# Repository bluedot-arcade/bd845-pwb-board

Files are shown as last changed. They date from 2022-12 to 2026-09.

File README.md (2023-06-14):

<p align="right">
    
      
</p>
<br><br>
<p align="center">
    <h1 align="center">BD845-PWB IO Board</h1>
    <p align="center">A clone of the original Konami GN845-PWB(B) Stage I/O board for DDR machines.</p>
    <p align="center"><strong><a href="https://github.com/bluedot-arcade/bd845-pwb-firmware">Go to firmware repository</a></strong></p>
    <p align="center"><strong><a href="https://docs.bluedotarcade.com/boards/bd845-pwb">Explore the docs</a></strong></p>
    <br><br>
</p>

<p align="center">A render of the board from the front.</p>

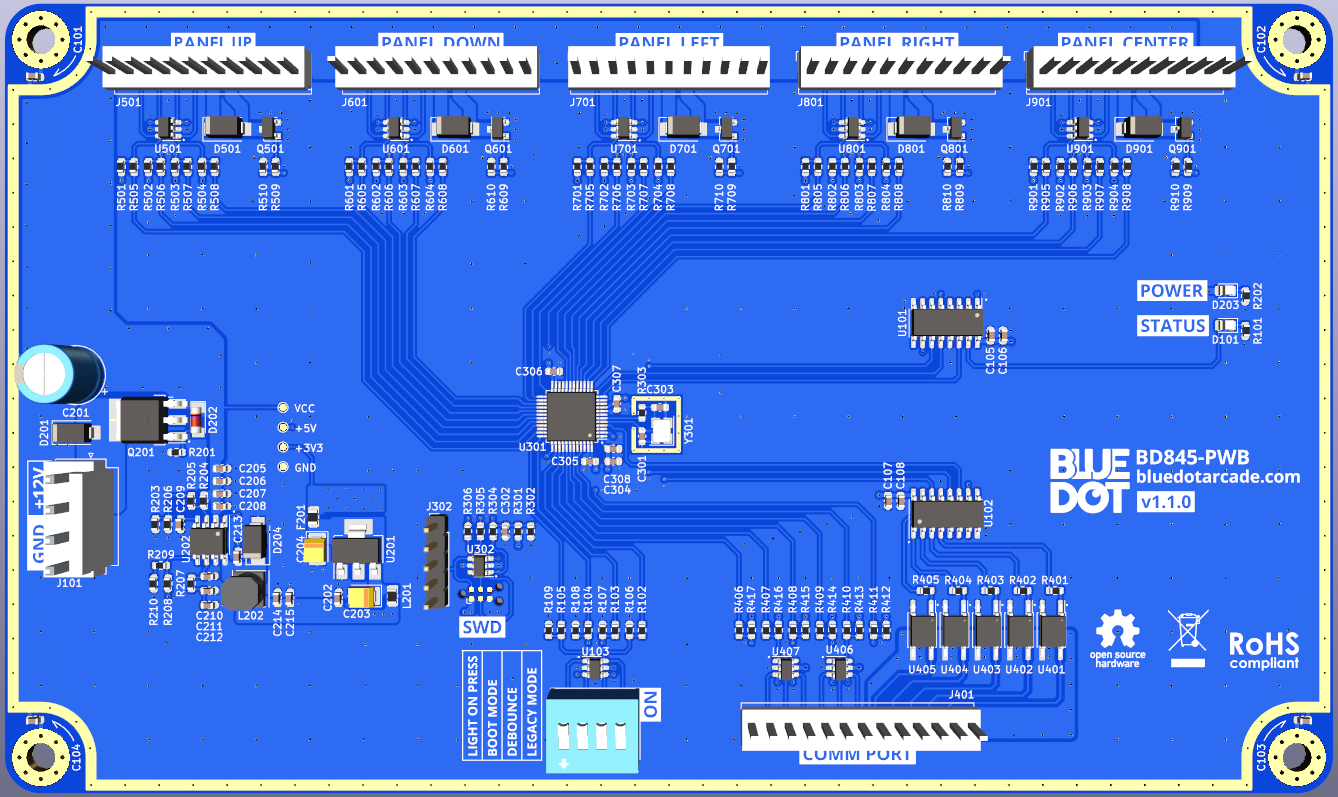
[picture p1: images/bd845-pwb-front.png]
BD845-PWB Front


## About the project

The goal of the project is to replicate the original Konami GN845-PWB(B) Stage I/O board by designing a drop in replacement board for future-proofing DDR cabinets.

It emulates the original DDR Stage I/O communication protocol boot sequence allowing to run the game without an I/O Check Bypass. Other protocol features are currently not supported.

It also provides additional features such as debouncing and a Light-On-Press mode that lights up the arrow light when pressed without the need of an external lights driver board.

The board can be re-programmed with a custom/updated firmware. The latest version of the firmware can be found [here](https://github.com/bluedot-arcade/bd845-pwb-firmware).

For more information read the [docs](https://docs.bluedotarcade.com/boards/bd845-pwb).

<p align="right">(<a href="#readme-top">back to top</a>)</p>

## Project structure

* [/fab/](/fab/) - the files required for fabbrication that includes gerbers, drills and assembly files.
* [/kicad/](/kicad/) -  the kicad project files.
* [/images/](/images/) - images and renders.
* [/sch_bd845-pwb.pdf](/sch_bd845-pwb.pdf) - the board's schematic.
* [/draw_bd845-pwb.pdf](/draw_bd845-pwb.pdf) - the board's mechanical drawings.
* [/bom_bd845-pwb.csv](/bom_bd845-pwb.csv) - the board's bill of materials.
* [/ibom_bd845-pwb.html](/ibom_bd845-pwb.html) - an interactive bill of materials very useful for manual assembly.

<p align="right">(<a href="#readme-top">back to top</a>)</p>

## Images and renders

PCB Front layer:

BD845-PWB Front

PCB Back layer:

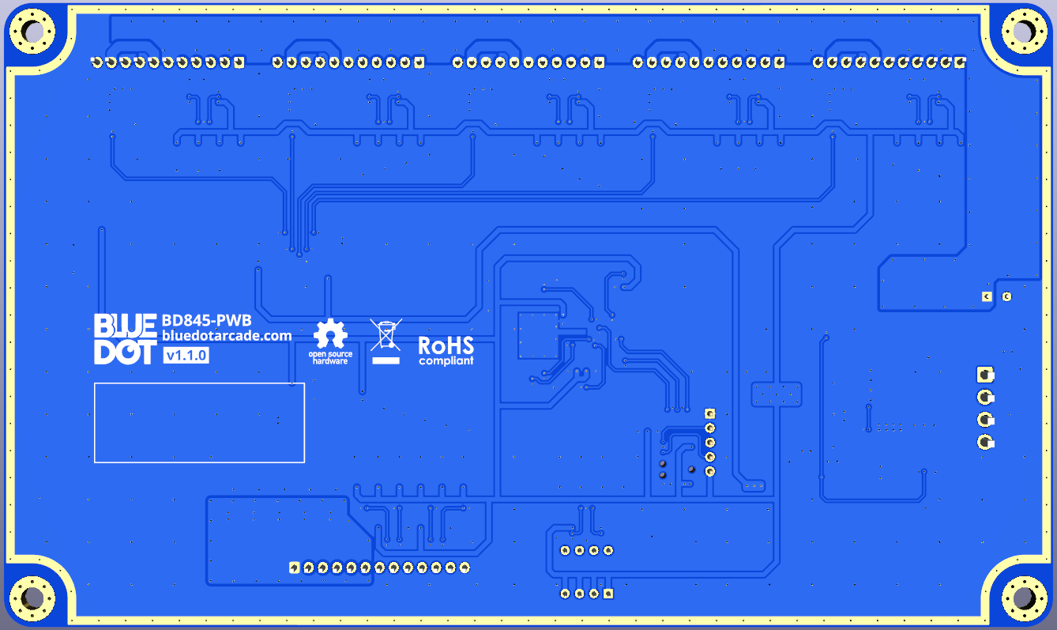
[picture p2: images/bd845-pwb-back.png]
BD845-PWB Back


Original Konami GN845-PWB:

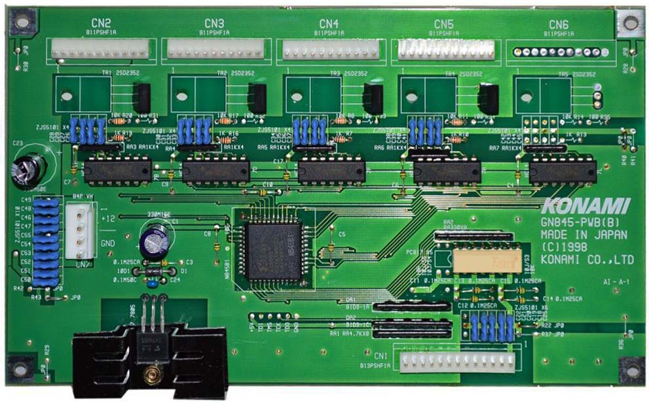
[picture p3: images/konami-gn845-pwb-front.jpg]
GN845-PWB Front


<p align="right">(<a href="#readme-top">back to top</a>)</p>

## License

Distributed under the CERN OHL S 2 License. See [LICENSE.txt] for more information.

<p align="right">(<a href="#readme-top">back to top</a>)</p>

## Acknowledgments

* [NaokiS] - for providing valuable information about the original DDR stage IO communication protocol.
* [Marco Ruggiero] - for designing the BlueDot logo and beta-testing the board on its own cabinet.
* [Mattia Pini] - for lending me his KSYS573 computer to carry out tests.
* [MameDev] - for opensourcing the KSYS573 Boot IO check emulation which this board is based on.
* [InteractiveHtmlBom] - the Kicad plugin used to generate the interactive BOM.
* [Kicad] - for allowing me to design this board for free!

<p align="right">(<a href="#readme-top">back to top</a>)</p>

[NaokiS]: http://nsaito.co.uk/
[Marco Ruggiero]: https://www.instagram.com/ruggiero.design/
[Mattia Pini]: https://github.com/martirius
[MameDev]: https://github.com/mamedev/mame/blob/master/src/mame/konami/ksys573.cpp
[InteractiveHtmlBom]: https://github.com/openscopeproject/InteractiveHtmlBom
[Kicad]: https://www.kicad.org/
[LICENSE.txt]: /LICENSE.txtschematic

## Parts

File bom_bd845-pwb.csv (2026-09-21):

Reference | Value | Footprint | Datasheet | JLCPCB Part #
C101 | 1n | Capacitor_SMD:C_0603_1608Metric |  | C1588
C102 | 1n | Capacitor_SMD:C_0603_1608Metric |  | C1588
C103 | 1n | Capacitor_SMD:C_0603_1608Metric |  | C1588
C104 | 1n | Capacitor_SMD:C_0603_1608Metric |  | C1588
C105 | 10n | Capacitor_SMD:C_0603_1608Metric |  | C57112
C106 | 100n | Capacitor_SMD:C_0603_1608Metric |  | C14663
C107 | 100n | Capacitor_SMD:C_0603_1608Metric |  | C14663
C108 | 10n | Capacitor_SMD:C_0603_1608Metric |  | C57112
C201 | 330u | Capacitor_THT:CP_Radial_D8.0mm_P3.50mm |  | C109394
C202 | 100n | Capacitor_SMD:C_0603_1608Metric |  | C14663
C203 | 22u | Capacitor_Tantalum_SMD:CP_EIA-3528-15_AVX-H |  | C8020
C204 | 22u | Capacitor_Tantalum_SMD:CP_EIA-3528-15_AVX-H |  | C8020
C205 | 10u | Capacitor_SMD:C_0603_1608Metric |  | C96446
C206 | 10u | Capacitor_SMD:C_0603_1608Metric |  | C96446
C207 | 10n | Capacitor_SMD:C_0603_1608Metric |  | C57112
C208 | 1n | Capacitor_SMD:C_0603_1608Metric |  | C1588
C209 | 10n | Capacitor_SMD:C_0603_1608Metric |  | C57112
C210 | 6p8 | Capacitor_SMD:C_0603_1608Metric |  | C1679
C211 | 2n7 | Capacitor_SMD:C_0603_1608Metric |  | C1609
C212 | 2n7 | Capacitor_SMD:C_0603_1608Metric |  | C1609
C213 | 100n | Capacitor_SMD:C_0603_1608Metric |  | C14663
C214 | 10u | Capacitor_SMD:C_0603_1608Metric |  | C96446
C215 | 10u | Capacitor_SMD:C_0603_1608Metric |  | C96446
C301 | 10p | Capacitor_SMD:C_0603_1608Metric |  | C1634
C302 | 100n | Capacitor_SMD:C_0603_1608Metric |  | C14663
C303 | 10p | Capacitor_SMD:C_0603_1608Metric |  | C1634
C304 | 10u | Capacitor_SMD:C_0603_1608Metric |  | C96446
C305 | 100n | Capacitor_SMD:C_0603_1608Metric |  | C14663
C306 | 100n | Capacitor_SMD:C_0603_1608Metric |  | C14663
C307 | 100n | Capacitor_SMD:C_0603_1608Metric |  | C14663
C308 | 100n | Capacitor_SMD:C_0603_1608Metric |  | C14663
D101 | Status | LED_SMD:LED_0805_2012Metric |  | C2296
D201 | SMAJ15CA | Diode_SMD:D_SMA |  | C19077536
D202 | 5V6 | Diode_SMD:D_MiniMELF |  | C19077402
D203 | Power | LED_SMD:LED_0805_2012Metric |  | C2297
D204 | SS34 | Diode_SMD:D_SMA |  | C8678
D501 | SS34 | Diode_SMD:D_SMA |  | C8678
D601 | SS34 | Diode_SMD:D_SMA |  | C8678
D701 | SS34 | Diode_SMD:D_SMA |  | C8678
D801 | SS34 | Diode_SMD:D_SMA |  | C8678
D901 | SS34 | Diode_SMD:D_SMA |  | C8678
F201 | BSMD0805-035 | Fuse:Fuse_0805_2012Metric |  | C883107
H101 | MountingHole_Pad | MountingHole:MountingHole_4mm_Pad_Via
H102 | MountingHole_Pad | MountingHole:MountingHole_4mm_Pad_Via
H103 | MountingHole_Pad | MountingHole:MountingHole_4mm_Pad_Via
H104 | MountingHole_Pad | MountingHole:MountingHole_4mm_Pad_Via
J101 | JST_VH_B4P | Connector_JST:JST_VH_B4P-VH_1x04_P3.96mm_Vertical |  | C493148
J301 | TC2030-MCP-NL | Connector:Tag-Connect_TC2030-IDC-NL_2x03_P1.27mm_Vertical | http://ww1.microchip.com/downloads/en/DeviceDoc/TC2030-MCP-NL_PCB_Footprint_RevD.pdf
J302 | PinHeader_01x05 | Connector_PinHeader_2.54mm:PinHeader_1x05_P2.54mm_Vertical |  | C6332198
J401 | JST_B13P_SHF_1AA | ProjectLibrary:JST_NH_B13P-SHF-1AA_1x13_P2.50mm_Vertical |  | C160368
J501 | JST_B11P_SHF_1AA | ProjectLibrary:JST_NH_B11P-SHF-1AA_1x11_P2.50mm_Vertical |  | C160366
J601 | JST_B11P_SHF_1AA | ProjectLibrary:JST_NH_B11P-SHF-1AA_1x11_P2.50mm_Vertical |  | C160366
J701 | JST_B11P_SHF_1AA | ProjectLibrary:JST_NH_B11P-SHF-1AA_1x11_P2.50mm_Vertical |  | C160366
J801 | JST_B11P_SHF_1AA | ProjectLibrary:JST_NH_B11P-SHF-1AA_1x11_P2.50mm_Vertical |  | C160366
J901 | JST_B11P_SHF_1AA | ProjectLibrary:JST_NH_B11P-SHF-1AA_1x11_P2.50mm_Vertical |  | C160366
L201 | 100R | Resistor_SMD:R_0805_2012Metric |  | C1015
L202 | 22u | Inductor_SMD:L_Taiyo-Yuden_NR-50xx |  | C68434
Q201 | AOD409 | Package_TO_SOT_SMD:TO-252-3_TabPin2 | https://datasheet.lcsc.com/lcsc/1811091710_Alpha---Omega-Semicon-AOD409_C36220.pdf | C36220
Q501 | ZXMS6004FFTA | ProjectLibrary:SOT23F | https://datasheet.lcsc.com/lcsc/2005131032_Diodes-Incorporated-ZXMS6004FFTA_C95063.pdf | C95063
Q601 | ZXMS6004FFTA | ProjectLibrary:SOT23F | https://datasheet.lcsc.com/lcsc/2005131032_Diodes-Incorporated-ZXMS6004FFTA_C95063.pdf | C95063
Q701 | ZXMS6004FFTA | ProjectLibrary:SOT23F | https://datasheet.lcsc.com/lcsc/2005131032_Diodes-Incorporated-ZXMS6004FFTA_C95063.pdf | C95063
Q801 | ZXMS6004FFTA | ProjectLibrary:SOT23F | https://datasheet.lcsc.com/lcsc/2005131032_Diodes-Incorporated-ZXMS6004FFTA_C95063.pdf | C95063
Q901 | ZXMS6004FFTA | ProjectLibrary:SOT23F | https://datasheet.lcsc.com/lcsc/2005131032_Diodes-Incorporated-ZXMS6004FFTA_C95063.pdf | C95063
R101 | 1k | Resistor_SMD:R_0603_1608Metric |  | C21190
R102 | 150R | Resistor_SMD:R_0603_1608Metric |  | C22808
R103 | 150R | Resistor_SMD:R_0603_1608Metric |  | C22808
R104 | 150R | Resistor_SMD:R_0603_1608Metric |  | C22808
R105 | 150R | Resistor_SMD:R_0603_1608Metric |  | C22808
R106 | 10k | Resistor_SMD:R_0603_1608Metric |  | C25804
R107 | 10k | Resistor_SMD:R_0603_1608Metric |  | C25804
R108 | 10k | Resistor_SMD:R_0603_1608Metric |  | C25804
R109 | 10k | Resistor_SMD:R_0603_1608Metric |  | C25804
R201 | 10k | Resistor_SMD:R_0603_1608Metric |  | C25804
R202 | 1k | Resistor_SMD:R_0603_1608Metric |  | C21190
R203 | 10k | Resistor_SMD:R_0603_1608Metric |  | C25804
R204 | 100k | Resistor_SMD:R_0603_1608Metric |  | C25803
R205 | 10k | Resistor_SMD:R_0603_1608Metric |  | C25804
R206 | 10k | Resistor_SMD:R_0603_1608Metric |  | C25804
R207 | 6k8 | Resistor_SMD:R_0603_1608Metric |  | C23212
R208 | 10k | Resistor_SMD:R_0603_1608Metric |  | C25804
R209 | 150R | Resistor_SMD:R_0603_1608Metric |  | C22808
R210 | 1k8 | Resistor_SMD:R_0603_1608Metric |  | C4177
R301 | 10k | Resistor_SMD:R_0603_1608Metric |  | C25804
R302 | NC | Resistor_SMD:R_0603_1608Metric
R303 | 47R | Resistor_SMD:R_0603_1608Metric |  | C23182
R304 | 150R | Resistor_SMD:R_0603_1608Metric |  | C22808
R305 | 150R | Resistor_SMD:R_0603_1608Metric |  | C22808
R306 | 150R | Resistor_SMD:R_0603_1608Metric |  | C22808
R401 | 330R | Resistor_SMD:R_0603_1608Metric |  | C23138
R402 | 330R | Resistor_SMD:R_0603_1608Metric |  | C23138
R403 | 330R | Resistor_SMD:R_0603_1608Metric |  | C23138
R404 | 330R | Resistor_SMD:R_0603_1608Metric |  | C23138
R405 | 330R | Resistor_SMD:R_0603_1608Metric |  | C23138
R406 | 150R | Resistor_SMD:R_0603_1608Metric |  | C22808
R407 | 150R | Resistor_SMD:R_0603_1608Metric |  | C22808
R408 | 150R | Resistor_SMD:R_0603_1608Metric |  | C22808
R409 | 150R | Resistor_SMD:R_0603_1608Metric |  | C22808
R410 | 150R | Resistor_SMD:R_0603_1608Metric |  | C22808
R411 | 150R | Resistor_SMD:R_0603_1608Metric |  | C22808
R412 | 10k | Resistor_SMD:R_0603_1608Metric |  | C25804
R413 | 10k | Resistor_SMD:R_0603_1608Metric |  | C25804
R414 | 10k | Resistor_SMD:R_0603_1608Metric |  | C25804
R415 | 10k | Resistor_SMD:R_0603_1608Metric |  | C25804
R416 | 10k | Resistor_SMD:R_0603_1608Metric |  | C25804
R417 | 10k | Resistor_SMD:R_0603_1608Metric |  | C25804
R501 | 10k | Resistor_SMD:R_0603_1608Metric |  | C25804
R502 | 10k | Resistor_SMD:R_0603_1608Metric |  | C25804
R503 | 10k | Resistor_SMD:R_0603_1608Metric |  | C25804
R504 | 10k | Resistor_SMD:R_0603_1608Metric |  | C25804
R505 | 150R | Resistor_SMD:R_0603_1608Metric |  | C22808
R506 | 150R | Resistor_SMD:R_0603_1608Metric |  | C22808
R507 | 150R | Resistor_SMD:R_0603_1608Metric |  | C22808
R508 | 150R | Resistor_SMD:R_0603_1608Metric |  | C22808
R509 | 0R | Resistor_SMD:R_0603_1608Metric |  | C21189
R510 | 10k | Resistor_SMD:R_0603_1608Metric |  | C25804
R601 | 10k | Resistor_SMD:R_0603_1608Metric |  | C25804
R602 | 10k | Resistor_SMD:R_0603_1608Metric |  | C25804
R603 | 10k | Resistor_SMD:R_0603_1608Metric |  | C25804
R604 | 10k | Resistor_SMD:R_0603_1608Metric |  | C25804
R605 | 150R | Resistor_SMD:R_0603_1608Metric |  | C22808
R606 | 150R | Resistor_SMD:R_0603_1608Metric |  | C22808
R607 | 150R | Resistor_SMD:R_0603_1608Metric |  | C22808
R608 | 150R | Resistor_SMD:R_0603_1608Metric |  | C22808
R609 | 0R | Resistor_SMD:R_0603_1608Metric |  | C21189
R610 | 10k | Resistor_SMD:R_0603_1608Metric |  | C25804
R701 | 10k | Resistor_SMD:R_0603_1608Metric |  | C25804
R702 | 10k | Resistor_SMD:R_0603_1608Metric |  | C25804
R703 | 10k | Resistor_SMD:R_0603_1608Metric |  | C25804
R704 | 10k | Resistor_SMD:R_0603_1608Metric |  | C25804
R705 | 150R | Resistor_SMD:R_0603_1608Metric |  | C22808
R706 | 150R | Resistor_SMD:R_0603_1608Metric |  | C22808
R707 | 150R | Resistor_SMD:R_0603_1608Metric |  | C22808
R708 | 150R | Resistor_SMD:R_0603_1608Metric |  | C22808
R709 | 0R | Resistor_SMD:R_0603_1608Metric |  | C21189
R710 | 10k | Resistor_SMD:R_0603_1608Metric |  | C25804
R801 | 10k | Resistor_SMD:R_0603_1608Metric |  | C25804
R802 | 10k | Resistor_SMD:R_0603_1608Metric |  | C25804
R803 | 10k | Resistor_SMD:R_0603_1608Metric |  | C25804
R804 | 10k | Resistor_SMD:R_0603_1608Metric |  | C25804
R805 | 150R | Resistor_SMD:R_0603_1608Metric |  | C22808
R806 | 150R | Resistor_SMD:R_0603_1608Metric |  | C22808
R807 | 150R | Resistor_SMD:R_0603_1608Metric |  | C22808
R808 | 150R | Resistor_SMD:R_0603_1608Metric |  | C22808
R809 | 0R | Resistor_SMD:R_0603_1608Metric |  | C21189
R810 | 10k | Resistor_SMD:R_0603_1608Metric |  | C25804
R901 | 10k | Resistor_SMD:R_0603_1608Metric |  | C25804
R902 | 10k | Resistor_SMD:R_0603_1608Metric |  | C25804
R903 | 10k | Resistor_SMD:R_0603_1608Metric |  | C25804
R904 | 10k | Resistor_SMD:R_0603_1608Metric |  | C25804
R905 | 150R | Resistor_SMD:R_0603_1608Metric |  | C22808
R906 | 150R | Resistor_SMD:R_0603_1608Metric |  | C22808
R907 | 150R | Resistor_SMD:R_0603_1608Metric |  | C22808
R908 | 150R | Resistor_SMD:R_0603_1608Metric |  | C22808
R909 | 0R | Resistor_SMD:R_0603_1608Metric |  | C21189
R910 | 10k | Resistor_SMD:R_0603_1608Metric |  | C25804
SW101 | SW_DIP_x04 | Button_Switch_THT:SW_DIP_SPSTx04_Slide_9.78x12.34mm_W7.62mm_P2.54mm |  | C692502
TP201 | TestPoint_Small | TestPoint:TestPoint_Pad_D1.0mm
TP202 | TestPoint_Small | TestPoint:TestPoint_Pad_D1.0mm
TP203 | TestPoint_Small | TestPoint:TestPoint_Pad_D1.0mm
TP204 | TestPoint_Small | TestPoint:TestPoint_Pad_D1.0mm
U101 | 74HC595-Q100 | Package_SO:SO-16_3.9x9.9mm_P1.27mm | http://www.ti.com/lit/ds/symlink/sn74hc595.pdf | C5947
U102 | 74HC595 | Package_SO:SO-16_3.9x9.9mm_P1.27mm | http://www.ti.com/lit/ds/symlink/sn74hc595.pdf | C5947
U103 | SRV05-4 | Package_TO_SOT_SMD:SOT-23-6 | http://www.onsemi.com/pub/Collateral/SRV05-4-D.PDF | C85364
U201 | AMS1117-3.3 | Package_TO_SOT_SMD:SOT-223-3_TabPin2 | http://www.advanced-monolithic.com/pdf/ds1117.pdf | C6186
U202 | TPS54331 | Package_SO:SOIC-8_3.9x4.9mm_P1.27mm | https://www.ti.com/lit/ds/symlink/tps54331.pdf | C9865
U301 | STM32F030C8Tx | Package_QFP:LQFP-48_7x7mm_P0.5mm | http://www.st.com/st-web-ui/static/active/en/resource/technical/document/datasheet/DM00088500.pdf | C23922
U302 | SRV05-4 | Package_TO_SOT_SMD:SOT-23-6 | http://www.onsemi.com/pub/Collateral/SRV05-4-D.PDF | C85364
U401 | EL357N(C)(TA)-G | Package_SO:SO-4_4.4x3.6mm_P2.54mm | https://datasheet.lcsc.com/lcsc/1810271030_Everlight-Elec-EL357N-C-TA-G_C29981.pdf | C42432283
U402 | EL357N(C)(TA)-G | Package_SO:SO-4_4.4x3.6mm_P2.54mm | https://datasheet.lcsc.com/lcsc/1810271030_Everlight-Elec-EL357N-C-TA-G_C29981.pdf | C42432283
U403 | EL357N(C)(TA)-G | Package_SO:SO-4_4.4x3.6mm_P2.54mm | https://datasheet.lcsc.com/lcsc/1810271030_Everlight-Elec-EL357N-C-TA-G_C29981.pdf | C42432283
U404 | EL357N(C)(TA)-G | Package_SO:SO-4_4.4x3.6mm_P2.54mm | https://datasheet.lcsc.com/lcsc/1810271030_Everlight-Elec-EL357N-C-TA-G_C29981.pdf | C42432283
U405 | EL357N(C)(TA)-G | Package_SO:SO-4_4.4x3.6mm_P2.54mm | https://datasheet.lcsc.com/lcsc/1810271030_Everlight-Elec-EL357N-C-TA-G_C29981.pdf | C42432283
U406 | SRV05-4 | Package_TO_SOT_SMD:SOT-23-6 | http://www.onsemi.com/pub/Collateral/SRV05-4-D.PDF | C85364
U407 | SRV05-4 | Package_TO_SOT_SMD:SOT-23-6 | http://www.onsemi.com/pub/Collateral/SRV05-4-D.PDF | C85364
U501 | SRV05-4 | Package_TO_SOT_SMD:SOT-23-6 | http://www.onsemi.com/pub/Collateral/SRV05-4-D.PDF | C85364
U601 | SRV05-4 | Package_TO_SOT_SMD:SOT-23-6 | http://www.onsemi.com/pub/Collateral/SRV05-4-D.PDF | C85364
U701 | SRV05-4 | Package_TO_SOT_SMD:SOT-23-6 | http://www.onsemi.com/pub/Collateral/SRV05-4-D.PDF | C85364
U801 | SRV05-4 | Package_TO_SOT_SMD:SOT-23-6 | http://www.onsemi.com/pub/Collateral/SRV05-4-D.PDF | C85364
U901 | SRV05-4 | Package_TO_SOT_SMD:SOT-23-6 | http://www.onsemi.com/pub/Collateral/SRV05-4-D.PDF | C85364
Y301 | 16Mhz | Crystal:Crystal_SMD_3225-4Pin_3.2x2.5mm |  | C13738

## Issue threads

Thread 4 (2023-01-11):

PCB: Fix asimmetrical track on R808.

vinsfortunato, 2023-01-11:
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

Closed 2023-06-13.

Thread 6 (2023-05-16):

Add fuse on +12V rail.

vinsfortunato, 2023-05-16:
Add a swappable fuse after the input power connector to protect light circuitry from short-circuit.

Closed 2023-06-13.

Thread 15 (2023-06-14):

Light driver short protection not working.

vinsfortunato, 2023-06-14:
Shorting light connector will cause the mosfet to instantly die. The current mosfet is rated for only 1W, so 12V across it will destroy it with as little as 83mA. Fuses will not kick in.

Closed 2023-06-16.

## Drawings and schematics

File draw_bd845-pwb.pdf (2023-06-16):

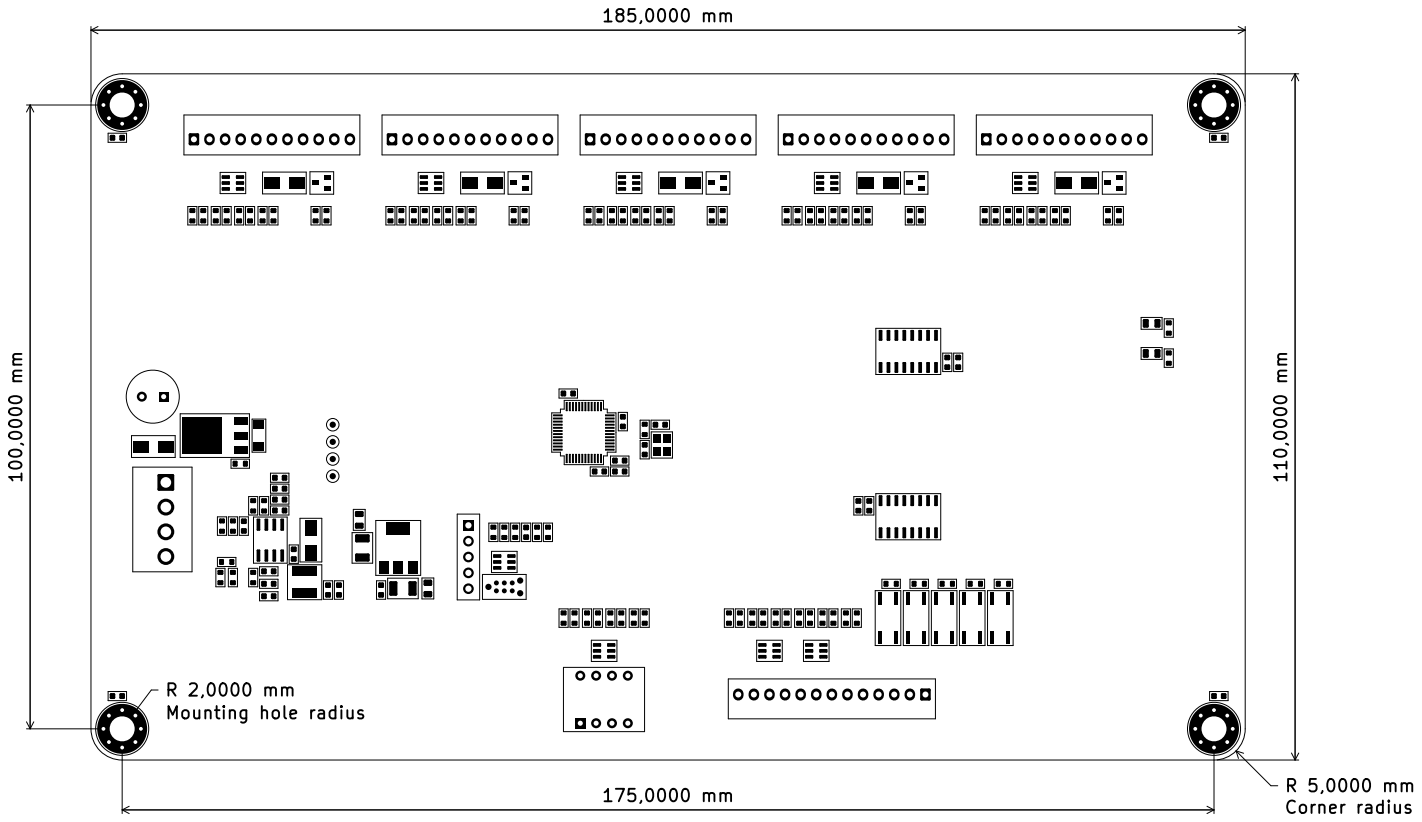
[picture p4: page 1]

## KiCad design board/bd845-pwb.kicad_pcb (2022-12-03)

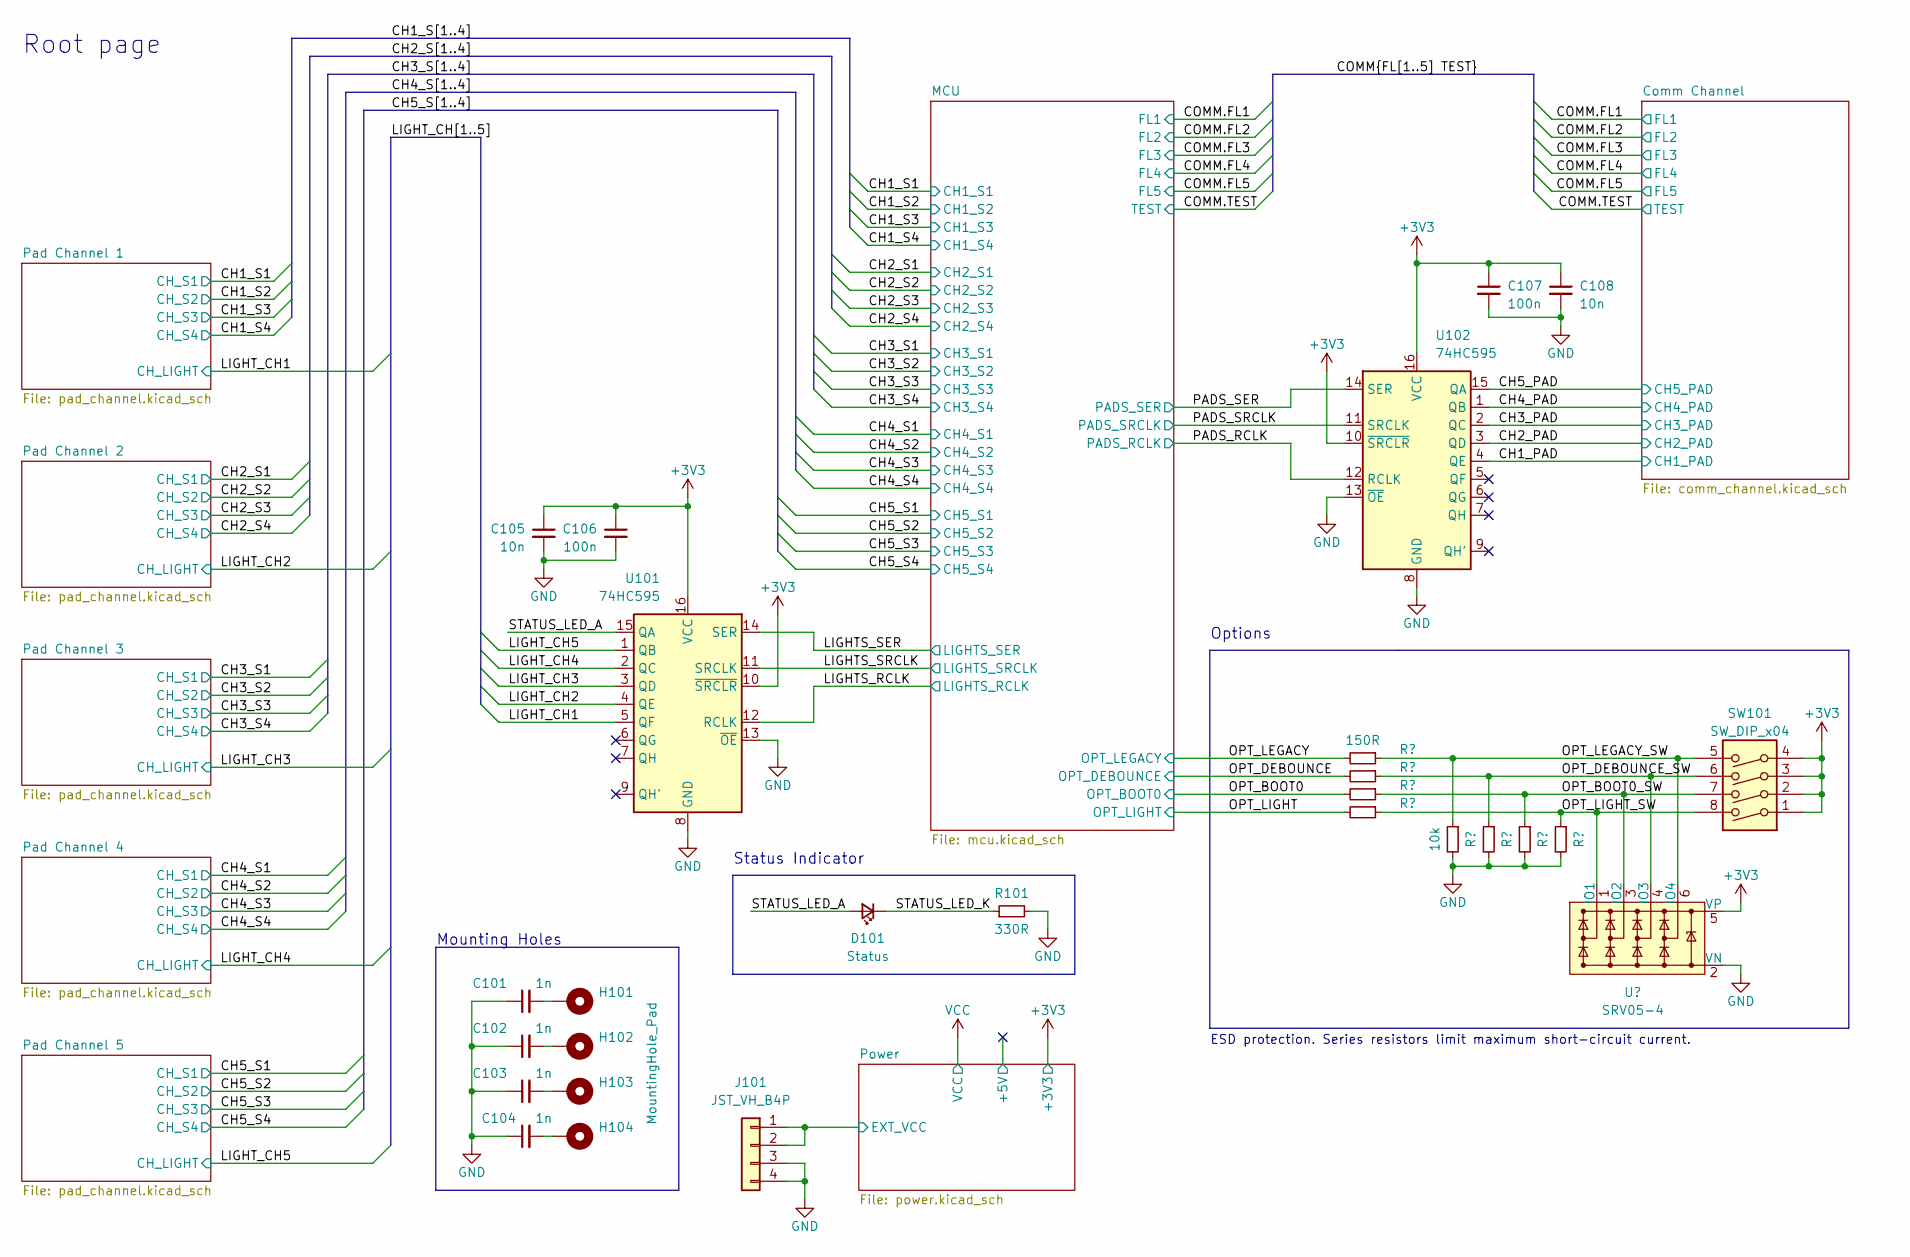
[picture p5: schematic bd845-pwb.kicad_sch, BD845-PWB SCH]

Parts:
C101, C102, C103, C104: 1n; C_0603_1608Metric
C105, C108: 10n; C_0603_1608Metric
C106, C107: 100n; C_0603_1608Metric
D101: Status; LED_0805_2012Metric
H101, H102, H103, H104: MountingHole_Pad; MountingHole_4mm_Pad_Via
J101: JST_VH_B4P; JST_VH_B4P-VH_1x04_P3.96mm_Vertical
R101: 330R; R_0603_1608Metric
R102, R103, R104, R105: 150R; R_0603_1608Metric
R106, R107, R108, R109: 10k; R_0603_1608Metric
SW101: SW_DIP_x04; SW_DIP_SPSTx04_Slide_9.78x12.34mm_W7.62mm_P2.54mm
U101, U102: 74HC595; SO-16_3.9x9.9mm_P1.27mm
U103: SRV05-4; SOT-23-6

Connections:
/CH1_PAD: U102.4 (QE); also elsewhere on the board
/CH2_PAD: U102.3 (QD); also elsewhere on the board
/CH3_PAD: U102.2 (QC); also elsewhere on the board
/CH4_PAD: U102.1 (QB); also elsewhere on the board
/CH5_PAD: U102.15 (QA); also elsewhere on the board
/LIGHTS_RCLK: U101.12 (RCLK); also elsewhere on the board
/LIGHTS_SER: U101.14 (SER); also elsewhere on the board
/LIGHTS_SRCLK: U101.11 (SRCLK); also elsewhere on the board
/LIGHT_CH1: U101.5 (QF); also elsewhere on the board
/LIGHT_CH2: U101.4 (QE); also elsewhere on the board
/LIGHT_CH3: U101.3 (QD); also elsewhere on the board
/LIGHT_CH4: U101.2 (QC); also elsewhere on the board
/LIGHT_CH5: U101.1 (QB); also elsewhere on the board
/OPT_BOOT0: R104.2; also elsewhere on the board
/OPT_COMP_MODE: R102.2; also elsewhere on the board
/OPT_DEBOUNCE: R103.2; also elsewhere on the board
/OPT_LIGHT_MODE: R105.2; also elsewhere on the board
/PADS_RCLK: U102.12 (RCLK); also elsewhere on the board
/PADS_SER: U102.14 (SER); also elsewhere on the board
/PADS_SRCLK: U102.11 (SRCLK); also elsewhere on the board
/Power/EXT_VCC: J101.1, J101.2; also elsewhere on the board
/STATUS_LED_A: D101.2 (A), U101.15 (QA)
/STATUS_LED_K: D101.1 (K), R101.1
GND: C101.1, C102.1, C103.1, C104.1, C105.2, C106.2, C107.2, C108.2, J101.3, J101.4, R101.2, R106.2, R107.2, R108.2, R109.2, U101.8 (GND), U101.13 (~OE), U102.8 (GND), U102.13 (~OE), U103.2 (VN); also elsewhere on the board
unnamed: C101.2, H101.1
unnamed: C102.2, H102.1
unnamed: C103.2, H103.1
unnamed: C104.2, H104.1

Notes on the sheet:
ESD protection. Series resistors limit maximum short-circuit current.
Root page
Options
Status Indicator
Mounting Holes

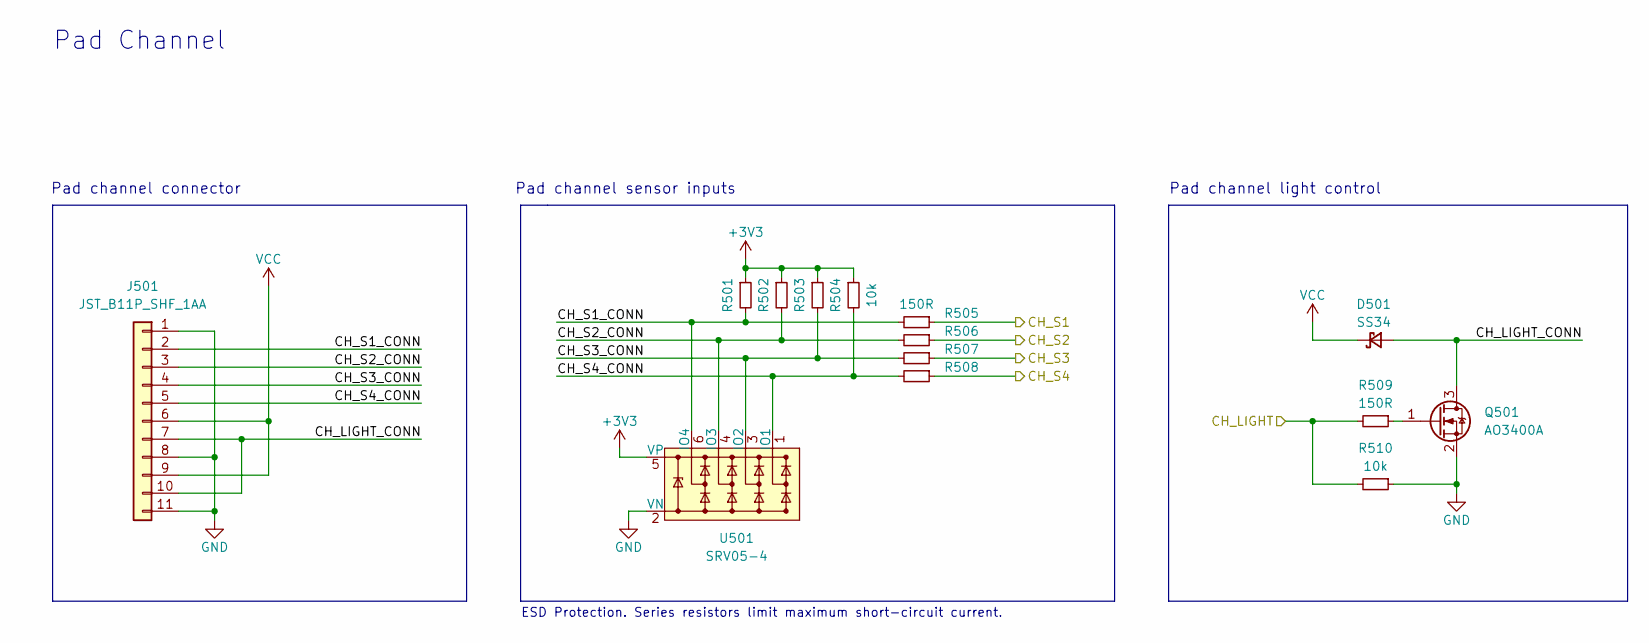
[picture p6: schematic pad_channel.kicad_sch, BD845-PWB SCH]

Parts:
D501: SS34; D_SMA
J501: JST_B11P_SHF_1AA; JST_NH_B11P-SHF-1AA_1x11_P2.50mm_Vertical
Q501: AO3400A; SOT-23
R501, R502, R503, R504, R510: 10k; R_0603_1608Metric
R505, R506, R507, R508, R509: 150R; R_0603_1608Metric
U501: SRV05-4; SOT-23-6

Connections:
/CH1_S1: R505.1; also elsewhere on the board
/CH1_S2: R506.1; also elsewhere on the board
/CH1_S3: R507.1; also elsewhere on the board
/CH1_S4: R508.1; also elsewhere on the board
/LIGHT_CH1: R509.2, R510.2; also elsewhere on the board
/Pad Channel 1/CH_LIGHT_CONN: D501.2 (A), J501.7, J501.10, Q501.3 (D)
/Pad Channel 1/CH_S1_CONN: J501.2, R501.2, R505.2, U501.6 (IO4)
/Pad Channel 1/CH_S2_CONN: J501.3, R502.2, R506.2, U501.4 (IO3)
/Pad Channel 1/CH_S3_CONN: J501.4, R503.2, R507.2, U501.3 (IO2)
/Pad Channel 1/CH_S4_CONN: J501.5, R504.2, R508.2, U501.1 (IO1)
GND: J501.1, J501.8, J501.11, Q501.2 (S), R510.1, U501.2 (VN); also elsewhere on the board
unnamed: Q501.1 (G), R509.1
VCC: D501.1 (K), J501.6, J501.9; also elsewhere on the board

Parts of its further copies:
J901: JST_B11P_SHF_1AA; JST_NH_B11P-SHF-1AA_1x11_P2.50mm_Vertical
Q601, Q701, Q801, Q901: AO3400A; SOT-23
R601, R602, R603, R604, R610, R701, R702, R703, R704, R710, R801, R802, R803, R804, R810, R901, R902, R903, R904, R910: 10k; R_0603_1608Metric
R605, R606, R607, R608, R609, R705, R706, R707, R708, R709, R805, R806, R807, R808, R809, R905, R906, R907, R908, R909: 150R; R_0603_1608Metric
U601, U701, U801, U901: SRV05-4; SOT-23-6

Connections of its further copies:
/CH2_S1: R605.1; also elsewhere on the board
/CH2_S2: R606.1; also elsewhere on the board
/CH2_S3: R607.1; also elsewhere on the board
/CH2_S4: R608.1; also elsewhere on the board
/CH3_S1: R705.1; also elsewhere on the board
/CH3_S2: R706.1; also elsewhere on the board
/CH3_S3: R707.1; also elsewhere on the board
/CH3_S4: R708.1; also elsewhere on the board
/CH4_S1: R805.1; also elsewhere on the board
/CH4_S2: R806.1; also elsewhere on the board
/CH4_S3: R807.1; also elsewhere on the board
/CH4_S4: R808.1; also elsewhere on the board
/CH5_S1: R905.1; also elsewhere on the board
/CH5_S2: R906.1; also elsewhere on the board
/CH5_S3: R907.1; also elsewhere on the board
/CH5_S4: R908.1; also elsewhere on the board
/LIGHT_CH2: R609.2, R610.2; also elsewhere on the board
/LIGHT_CH3: R709.2, R710.2; also elsewhere on the board
/LIGHT_CH4: R809.2, R810.2; also elsewhere on the board
/LIGHT_CH5: R909.2, R910.2; also elsewhere on the board
/Pad Channel 2/CH_LIGHT_CONN: Q601.3 (D); also elsewhere on the board
/Pad Channel 2/CH_S1_CONN: R601.2, R605.2, U601.6 (IO4); also elsewhere on the board
/Pad Channel 2/CH_S2_CONN: R602.2, R606.2, U601.4 (IO3); also elsewhere on the board
/Pad Channel 2/CH_S3_CONN: R603.2, R607.2, U601.3 (IO2); also elsewhere on the board
/Pad Channel 2/CH_S4_CONN: R604.2, R608.2, U601.1 (IO1); also elsewhere on the board
/Pad Channel 3/CH_LIGHT_CONN: Q701.3 (D); also elsewhere on the board
/Pad Channel 3/CH_S1_CONN: R701.2, R705.2, U701.6 (IO4); also elsewhere on the board
/Pad Channel 3/CH_S2_CONN: R702.2, R706.2, U701.4 (IO3); also elsewhere on the board
/Pad Channel 3/CH_S3_CONN: R703.2, R707.2, U701.3 (IO2); also elsewhere on the board
/Pad Channel 3/CH_S4_CONN: R704.2, R708.2, U701.1 (IO1); also elsewhere on the board
/Pad Channel 4/CH_LIGHT_CONN: Q801.3 (D); also elsewhere on the board
/Pad Channel 4/CH_S1_CONN: R801.2, R805.2, U801.6 (IO4); also elsewhere on the board
/Pad Channel 4/CH_S2_CONN: R802.2, R806.2, U801.4 (IO3); also elsewhere on the board
/Pad Channel 4/CH_S3_CONN: R803.2, R807.2, U801.3 (IO2); also elsewhere on the board
/Pad Channel 4/CH_S4_CONN: R804.2, R808.2, U801.1 (IO1); also elsewhere on the board
/Pad Channel 5/CH_LIGHT_CONN: J901.7, J901.10, Q901.3 (D); also elsewhere on the board
/Pad Channel 5/CH_S1_CONN: J901.2, R901.2, R905.2, U901.6 (IO4)
/Pad Channel 5/CH_S2_CONN: J901.3, R902.2, R906.2, U901.4 (IO3)
/Pad Channel 5/CH_S3_CONN: J901.4, R903.2, R907.2, U901.3 (IO2)
/Pad Channel 5/CH_S4_CONN: J901.5, R904.2, R908.2, U901.1 (IO1)
GND: J901.1, J901.8, J901.11, Q601.2 (S), Q701.2 (S), Q801.2 (S), Q901.2 (S), R610.1, R710.1, R810.1, R910.1, U601.2 (VN), U701.2 (VN), U801.2 (VN), U901.2 (VN); also elsewhere on the board
unnamed: Q601.1 (G), R609.1
unnamed: Q701.1 (G), R709.1
unnamed: Q801.1 (G), R809.1
unnamed: Q901.1 (G), R909.1
VCC: J901.6, J901.9; also elsewhere on the board

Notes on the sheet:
Pad channel connector
ESD Protection. Series resistors limit maximum short-circuit current.
Pad channel sensor inputs
Pad Channel
Pad channel light control

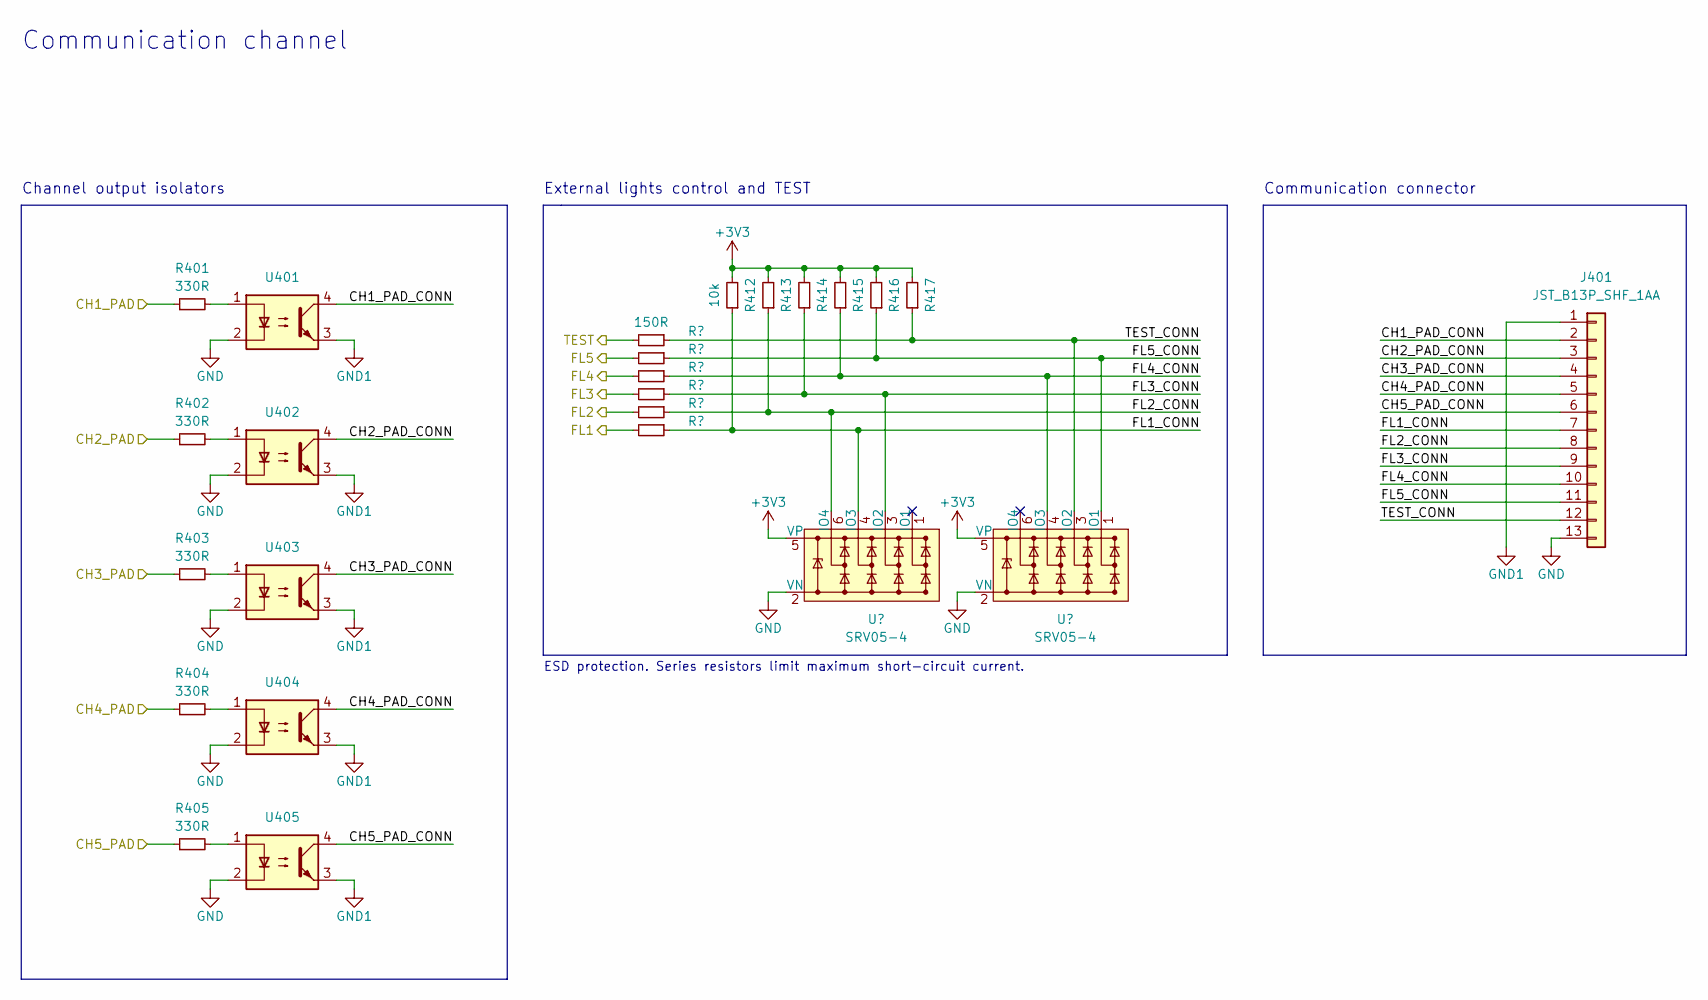
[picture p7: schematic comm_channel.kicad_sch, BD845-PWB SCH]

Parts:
J401: JST_B13P_SHF_1AA; JST_NH_B13P-SHF-1AA_1x13_P2.50mm_Vertical
R401, R402, R403, R404, R405: 330R; R_0603_1608Metric
R406, R407, R408, R409, R410, R411: 150R; R_0603_1608Metric
R412, R413, R414, R415, R416, R417: 10k; R_0603_1608Metric
U401, U402, U403, U404, U405: EL357N(C)(TA)-G; SO-4_4.4x3.6mm_P2.54mm
U406, U407: SRV05-4; SOT-23-6

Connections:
/CH1_PAD: R401.1; also elsewhere on the board
/CH2_PAD: R402.1; also elsewhere on the board
/CH3_PAD: R403.1; also elsewhere on the board
/CH4_PAD: R404.1; also elsewhere on the board
/CH5_PAD: R405.1; also elsewhere on the board
/COMM.FL1: R411.2; also elsewhere on the board
/COMM.FL2: R410.2; also elsewhere on the board
/COMM.FL3: R409.2; also elsewhere on the board
/COMM.FL4: R408.2; also elsewhere on the board
/COMM.FL5: R407.2; also elsewhere on the board
/COMM.TEST: R406.2; also elsewhere on the board
/Comm Channel/CH1_PAD_CONN: J401.2, U401.4
/Comm Channel/CH2_PAD_CONN: J401.3, U402.4
/Comm Channel/CH3_PAD_CONN: J401.4, U403.4
/Comm Channel/CH4_PAD_CONN: J401.5, U404.4
/Comm Channel/CH5_PAD_CONN: J401.6, U405.4
/Comm Channel/FL1_CONN: J401.7, R411.1, R412.1, U406.4 (IO3)
/Comm Channel/FL2_CONN: J401.8, R410.1, R413.1, U406.6 (IO4)
/Comm Channel/FL3_CONN: J401.9, R409.1, R414.1, U406.3 (IO2)
/Comm Channel/FL4_CONN: J401.10, R408.1, R415.1, U407.4 (IO3)
/Comm Channel/FL5_CONN: J401.11, R407.1, R416.1, U407.1 (IO1)
/Comm Channel/TEST_CONN: J401.12, R406.1, R417.1, U407.3 (IO2)
GND: J401.13, U401.2, U402.2, U403.2, U404.2, U405.2, U406.2 (VN), U407.2 (VN); also elsewhere on the board
GND1: J401.1, U401.3, U402.3, U403.3, U404.3, U405.3
unnamed: R401.2, U401.1
unnamed: R402.2, U402.1
unnamed: R403.2, U403.1
unnamed: R404.2, U404.1
unnamed: R405.2, U405.1

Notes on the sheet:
Communication connector
Channel output isolators
Communication channel
External lights control and TEST
ESD protection. Series resistors limit maximum short-circuit current.

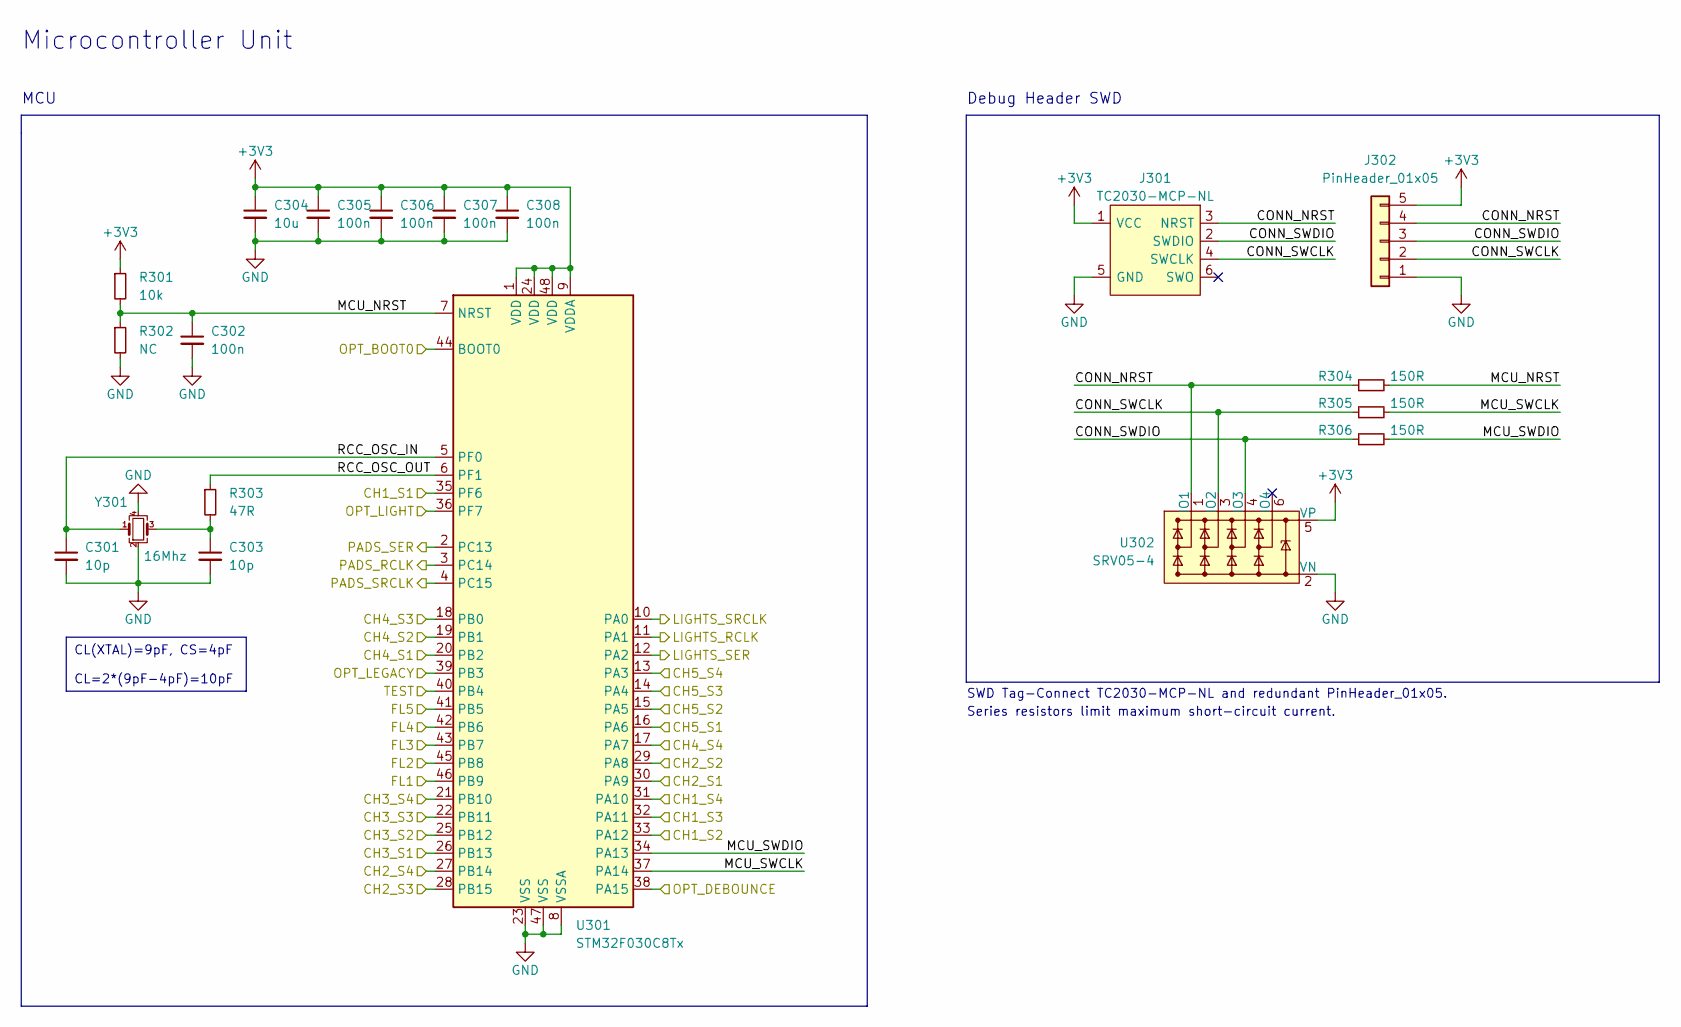
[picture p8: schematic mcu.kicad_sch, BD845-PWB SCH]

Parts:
C301, C303: 10p; C_0603_1608Metric
C302, C305, C306, C307, C308: 100n; C_0603_1608Metric
C304: 10u; C_0603_1608Metric
J301: TC2030-MCP-NL; Tag-Connect_TC2030-IDC-NL_2x03_P1.27mm_Vertical; Manufacturer_Part_Number TC2030-MCP-NL; Mouser Part Number 579-TC2030-MCP-NL
J302: PinHeader_01x05; PinHeader_1x05_P2.54mm_Vertical
R301: 10k; R_0603_1608Metric
R302: NC; R_0603_1608Metric
R303: 47R; R_0603_1608Metric
R304, R305, R306: 150R; R_0603_1608Metric
U301: STM32F030C8Tx; LQFP-48_7x7mm_P0.5mm
U302: SRV05-4; SOT-23-6
Y301: 16Mhz; Crystal_SMD_3225-4Pin_3.2x2.5mm

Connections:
/CH1_S1: U301.35 (PF6); also elsewhere on the board
/CH1_S2: U301.33 (PA12); also elsewhere on the board
/CH1_S3: U301.32 (PA11); also elsewhere on the board
/CH1_S4: U301.31 (PA10); also elsewhere on the board
/CH2_S1: U301.30 (PA9); also elsewhere on the board
/CH2_S2: U301.29 (PA8); also elsewhere on the board
/CH2_S3: U301.28 (PB15); also elsewhere on the board
/CH2_S4: U301.27 (PB14); also elsewhere on the board
/CH3_S1: U301.26 (PB13); also elsewhere on the board
/CH3_S2: U301.25 (PB12); also elsewhere on the board
/CH3_S3: U301.22 (PB11); also elsewhere on the board
/CH3_S4: U301.21 (PB10); also elsewhere on the board
/CH4_S1: U301.20 (PB2); also elsewhere on the board
/CH4_S2: U301.19 (PB1); also elsewhere on the board
/CH4_S3: U301.18 (PB0); also elsewhere on the board
/CH4_S4: U301.17 (PA7); also elsewhere on the board
/CH5_S1: U301.16 (PA6); also elsewhere on the board
/CH5_S2: U301.15 (PA5); also elsewhere on the board
/CH5_S3: U301.14 (PA4); also elsewhere on the board
/CH5_S4: U301.13 (PA3); also elsewhere on the board
/COMM.FL1: U301.46 (PB9); also elsewhere on the board
/COMM.FL2: U301.45 (PB8); also elsewhere on the board
/COMM.FL3: U301.43 (PB7); also elsewhere on the board
/COMM.FL4: U301.42 (PB6); also elsewhere on the board
/COMM.FL5: U301.41 (PB5); also elsewhere on the board
/COMM.TEST: U301.40 (PB4); also elsewhere on the board
/LIGHTS_RCLK: U301.11 (PA1); also elsewhere on the board
/LIGHTS_SER: U301.12 (PA2); also elsewhere on the board
/LIGHTS_SRCLK: U301.10 (PA0); also elsewhere on the board
/MCU/CONN_NRST: J301.3 (NRST), J302.4, R304.1, U302.1 (IO1)
/MCU/CONN_SWCLK: J301.4 (SWCLK), J302.2, R305.1, U302.3 (IO2)
/MCU/CONN_SWDIO: J301.2 (SWDIO), J302.3, R306.1, U302.4 (IO3)
/MCU/MCU_NRST: C302.1, R301.2, R302.1, R304.2, U301.7 (NRST)
/MCU/MCU_SWCLK: R305.2, U301.37 (PA14)
/MCU/MCU_SWDIO: R306.2, U301.34 (PA13)
/MCU/RCC_OSC_IN: C301.1, U301.5 (PF0), Y301.1
/MCU/RCC_OSC_OUT: R303.1, U301.6 (PF1)
/OPT_BOOT0: U301.44 (BOOT0); also elsewhere on the board
/OPT_COMP_MODE: U301.39 (PB3); also elsewhere on the board
/OPT_DEBOUNCE: U301.38 (PA15); also elsewhere on the board
/OPT_LIGHT_MODE: U301.36 (PF7); also elsewhere on the board
/PADS_RCLK: U301.3 (PC14); also elsewhere on the board
/PADS_SER: U301.2 (PC13); also elsewhere on the board
/PADS_SRCLK: U301.4 (PC15); also elsewhere on the board
GND: C301.2, C302.2, C303.2, C304.2, C305.2, C306.2, C307.2, C308.2, J301.5 (GND), J302.1, R302.2, U301.8 (VSSA), U301.23 (VSS), U301.47 (VSS), U302.2 (VN), Y301.2, Y301.4; also elsewhere on the board
unnamed: C303.1, R303.2, Y301.3

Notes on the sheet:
CL(XTAL)=9pF, CS=4pF CL=2*(9pF-4pF)=10pF
Series resistors limit maximum short-circuit current.
SWD Tag-Connect TC2030-MCP-NL and redundant PinHeader_01x05.
MCU
Microcontroller Unit
Debug Header SWD

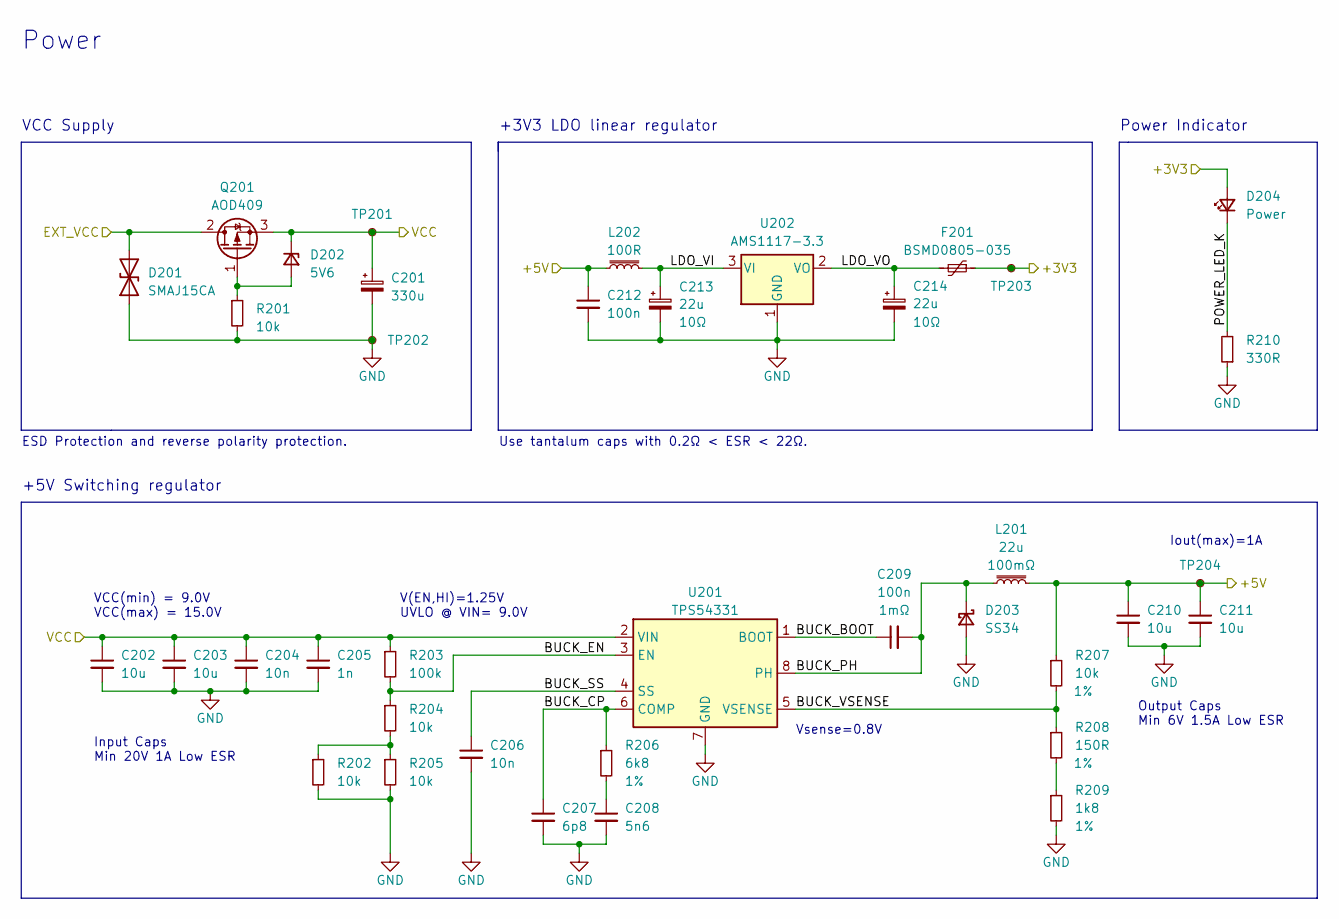
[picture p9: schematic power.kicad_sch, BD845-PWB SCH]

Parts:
C201: 330u; CP_Radial_D8.0mm_P3.50mm
C202, C203, C210, C211: 10u; C_0603_1608Metric
C204, C206: 10n; C_0603_1608Metric
C205: 1n; C_0603_1608Metric
C207: 6p8; C_0603_1608Metric
C208: 5n6; C_0603_1608Metric
C209, C212: 100n; C_0603_1608Metric
C213, C214: 22u; CP_EIA-3528-15_AVX-H
D201: SMAJ15CA; D_SMA
D202: 5V6; D_MiniMELF
D203: SS34; D_SMA
D204: Power; LED_0805_2012Metric
F201: BSMD0805-035; Fuse_0805_2012Metric
L201: 22u; L_Taiyo-Yuden_NR-50xx
L202: 100R; R_0805_2012Metric
Q201: AOD409; TO-252-3_TabPin2
R201, R202, R204, R205, R207: 10k; R_0603_1608Metric
R203: 100k; R_0603_1608Metric
R206: 6k8; R_0603_1608Metric
R208: 150R; R_0603_1608Metric
R209: 1k8; R_0603_1608Metric
R210: 330R; R_0603_1608Metric
TP201, TP202, TP203, TP204: TestPoint_Small; TestPoint_Pad_D1.0mm
U201: TPS54331; SOIC-8_3.9x4.9mm_P1.27mm
U202: AMS1117-3.3; SOT-223-3_TabPin2

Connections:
/Power/+5V: C210.1, C211.1, C212.1, L201.2, L202.1, R207.1, TP204.1
/Power/BUCK_BOOT: C209.1, U201.1 (BOOT)
/Power/BUCK_CP: C207.1, R206.1, U201.6 (COMP)
/Power/BUCK_EN: R203.2, R204.1, U201.3 (EN)
/Power/BUCK_PH: C209.2, D203.1 (K), L201.1, U201.8 (PH)
/Power/BUCK_SS: C206.1, U201.4 (SS)
/Power/BUCK_VSENSE: R207.2, R208.1, U201.5 (VSENSE)
/Power/EXT_VCC: D201.2 (A2), Q201.2 (D); also elsewhere on the board
/Power/LDO_VI: C213.1, L202.2, U202.3 (VI)
/Power/LDO_VO: C214.1, F201.2, U202.2 (VO)
/Power/POWER_LED_K: D204.1 (K), R210.2
GND: C201.2, C202.2, C203.2, C204.2, C205.2, C206.2, C207.2, C208.2, C210.2, C211.2, C212.2, C213.2, C214.2, D201.1 (A1), D203.2 (A), R201.2, R202.2, R205.2, R209.2, R210.1, TP202.1, U201.7 (GND), U202.1 (GND); also elsewhere on the board
unnamed: C208.1, R206.2
unnamed: D202.2 (A), Q201.1 (G), R201.1
unnamed: R202.1, R204.2, R205.1
unnamed: R208.2, R209.1
VCC: C201.1, C202.1, C203.1, C204.1, C205.1, D202.1 (K), Q201.3 (S), R203.1, TP201.1, U201.2 (VIN); also elsewhere on the board

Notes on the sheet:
Power Indicator
+3V3 LDO linear regulator
Iout(max)=1A
VCC(min) = 9.0V VCC(max) = 15.0V
+5V Switching regulator
V(EN,HI)=1.25V UVLO @ VIN= 9.0V
Output Caps Min 6V 1.5A Low ESR
Vsense=0.8V
Use tantalum caps with 0.2Ω < ESR < 22Ω.
ESD Protection and reverse polarity protection.
VCC Supply
Input Caps Min 20V 1A Low ESR
Power

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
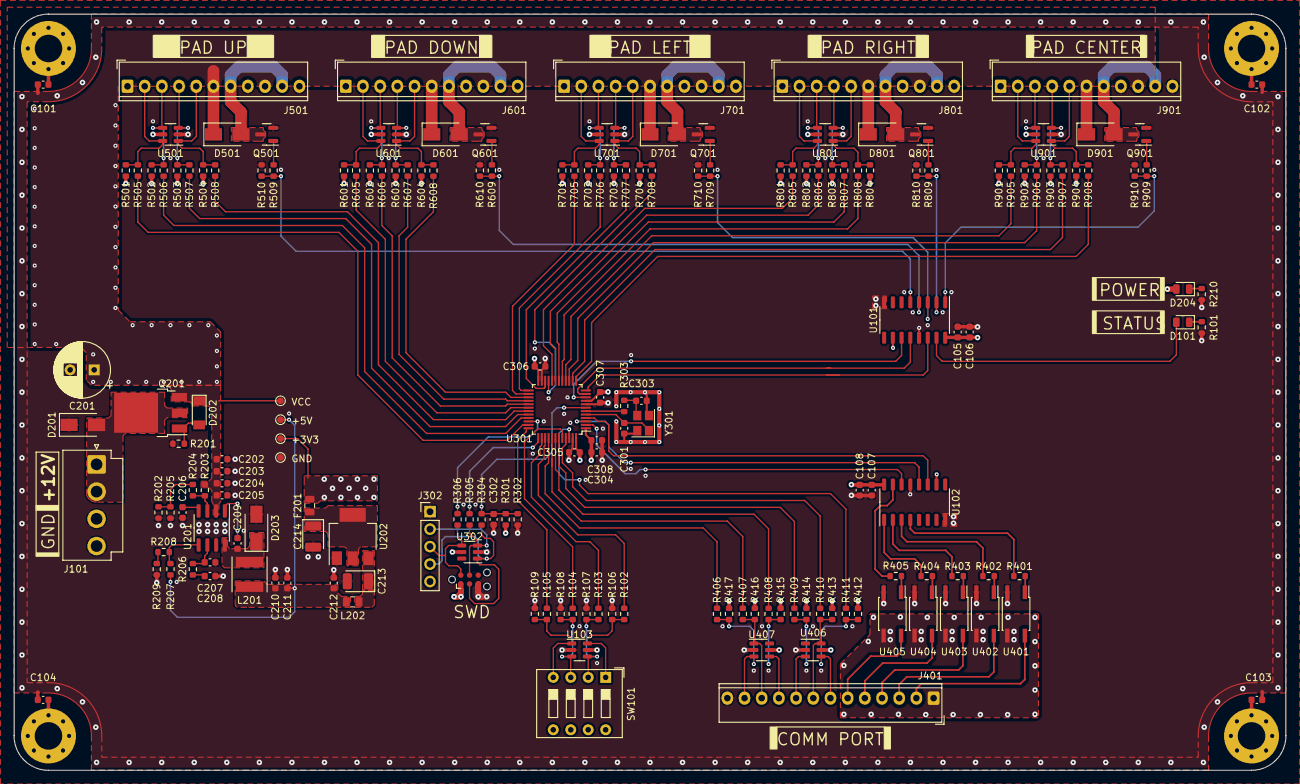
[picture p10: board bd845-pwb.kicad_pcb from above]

Board: 4 copper layers, 185.0 x 110.0 mm, 179 parts (0 on the bottom side), 130 nets.

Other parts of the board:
D601, D701, D801, D901: SS_34; D_SMA
J601, J701, J801: JST_B11P_XH_A; JST_NH_B11P-SHF-1AA_1x11_P2.50mm_Vertical

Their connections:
/Pad Channel 2/CH_LIGHT_CONN: D601.2 (A), J601.7, J601.10; also elsewhere on the board
/Pad Channel 2/CH_S1_CONN: J601.2; also elsewhere on the board
/Pad Channel 2/CH_S2_CONN: J601.3; also elsewhere on the board
/Pad Channel 2/CH_S3_CONN: J601.4; also elsewhere on the board
/Pad Channel 2/CH_S4_CONN: J601.5; also elsewhere on the board
/Pad Channel 3/CH_LIGHT_CONN: D701.2 (A), J701.7, J701.10; also elsewhere on the board
/Pad Channel 3/CH_S1_CONN: J701.2; also elsewhere on the board
/Pad Channel 3/CH_S2_CONN: J701.3; also elsewhere on the board
/Pad Channel 3/CH_S3_CONN: J701.4; also elsewhere on the board
/Pad Channel 3/CH_S4_CONN: J701.5; also elsewhere on the board
/Pad Channel 4/CH_LIGHT_CONN: D801.2 (A), J801.7, J801.10; also elsewhere on the board
/Pad Channel 4/CH_S1_CONN: J801.2; also elsewhere on the board
/Pad Channel 4/CH_S2_CONN: J801.3; also elsewhere on the board
/Pad Channel 4/CH_S3_CONN: J801.4; also elsewhere on the board
/Pad Channel 4/CH_S4_CONN: J801.5; also elsewhere on the board
/Pad Channel 5/CH_LIGHT_CONN: D901.2 (A); also elsewhere on the board
GND: J601.1, J601.8, J601.11, J701.1, J701.8, J701.11, J801.1, J801.8, J801.11; also elsewhere on the board
VCC: D601.1 (K), D701.1 (K), D801.1 (K), D901.1 (K), J601.6, J601.9, J701.6, J701.9, J801.6, J801.9; also elsewhere on the board

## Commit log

2022-11-26 Import project
    [bd845-pwb.kicad_pcb, bd845-pwb.kicad_sch, mcu.kicad_sch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]
2022-11-27 Update schematic
    [bd845-pwb.kicad_sch, comm_channel.kicad_sch, mcu.kicad_sch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]
2022-11-27 Remove unused schematic file
    [panel_channels.kicad_sch]
2022-11-29 Schematic done
    [bd845-pwb.kicad_pcb, bd845-pwb.kicad_sch, comm_channel.kicad_sch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]
2022-11-30 Update PCB
    [bd845-pwb.kicad_pcb, bd845-pwb.kicad_sch, comm_channel.kicad_sch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]
2022-12-13 Fill SCH and PCB Title Blocks
    [bd845-pwb-B_Cu (Sig-Pwr-Gnd).gbr, bd845-pwb-B_Mask.gbr, bd845-pwb-B_Paste.gbr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]
2022-12-13 Remove fab files
    [bd845-pwb-B_Cu (Sig-Pwr-Gnd).gbr, bd845-pwb-B_Mask.gbr, bd845-pwb-B_Paste.gbr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]
2022-12-14 Select input TVS diode
    [bd845-pwb.kicad_sch, bd845-pwb.xlsx, comm_channel.kicad_sch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]
2022-12-14 Update connectors color
    [power.kicad_sch]
2022-12-14 Update front PCB image
2023-01-04 Redefine PinNames.h definitions for custom board
2023-01-06 Import STM32Cube project
    [bd845-pwb Debug.cfg]
2023-05-16 Prepare for release v1.0.0
    [bd845-pwb-B_Cu (Sig-Pwr-Gnd).gbr, bd845-pwb-B_Mask.gbr, bd845-pwb-B_Paste.gbr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]
2023-05-16 Move firmware to external repository
    [bd845-pwb Debug.cfg]
2023-05-16 Refactor project structure
    [bd845-pwb-B_Cu (Sig-Pwr-Gnd).gbr, bd845-pwb-B_Mask.gbr, bd845-pwb-B_Paste.gbr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]
2023-05-17 Fix back to the top button in README.md
2023-05-20 Add "Go to firmware repository" link button
2023-06-13 Swap resistors and fix asymmetrical track on R808
2023-06-13 Fix unconnected +3V3 volt via.
2023-06-13 Swap capacitors near u102, move 10nF near IC
2023-06-13 Add PTC fuses on lights drivers and before switching regulator.
    [bd845-pwb.kicad_sch, comm_channel.kicad_sch, mcu.kicad_sch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]
2023-06-14 Update AMS1117 symbol
    [power.kicad_sch]
2023-06-14 Update to v1.1.0
    [bd845-pwb-B_Cu (Sig-Pwr-Gnd).gbr, bd845-pwb-B_Mask.gbr, bd845-pwb-B_Paste.gbr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]
2023-06-14 Split 5n6 capacitor into two separate caps
    [bd845-pwb.kicad_sch, comm_channel.kicad_sch, mcu.kicad_sch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]
2023-06-16 Change light driver to a self-protected mosfet. Remove unnecessary fuses. Change 74HC595 to low input voltage equivalent. Change LED resistors to 1k. Power lights shift register with +5V.
    [bd845-pwb.kicad_sch, pad_channel.kicad_sch, power.kicad_sch]
2023-06-16 Update bom, draw, ibon and sch files
    [bd845-pwb.kicad_sch, bom_bd845-pwb.csv, comm_channel.kicad_sch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]
2023-06-16 Update fab files
    [bd845-pwb-B_Cu (Sig-Pwr-Gnd).gbr, bd845-pwb-B_Mask.gbr, bd845-pwb-B_Paste.gbr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]
2024-10-24 Update BOM and position fabrication files
    [bd845-pwb.csv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]
2026-09-21 fab: update fabrication codes
    [bd845-pwb.csv]
2026-09-21 fab: update BOM with missing component codes
    [bd845-pwb.kicad_sch, bom_bd845-pwb.csv, comm_channel.kicad_sch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]

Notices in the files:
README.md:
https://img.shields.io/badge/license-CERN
